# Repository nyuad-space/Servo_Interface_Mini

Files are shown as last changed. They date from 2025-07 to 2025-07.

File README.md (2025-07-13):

# Servo Interface Mini

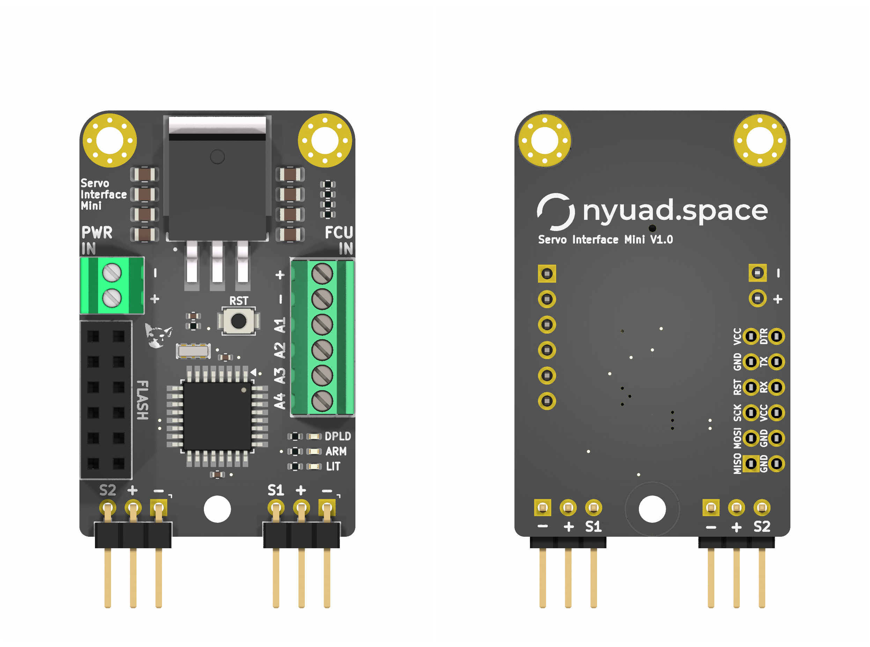
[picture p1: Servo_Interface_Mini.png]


## Overview

The **Servo Interface Mini** is a compact, flight-proven board built around the ATmega328P. It controls two servos via PWM based on logic changes on pyro channels. The board is part of our custom rocket parachute deployment system called the **Hold-Down Release Mechanism (HDRM)**.

It translates changes on pyro outputs from a flight computer into servo movement that actuates deployment hardware.

## Features

* **Microcontroller**: ATmega328P running Arduino-compatible firmware
* **Dual PWM Outputs**: Drives two standard hobby servos
* **Pyro Channel Triggering**: Responds to logic transitions on pyro lines
* **Status Indicators**: Onboard LEDs for deployment and system debugging
* **Power Supply**: Integrated LDO regulator supplies up to **5A at 5V** to servos and logic
* **Programming**: FTDI header for serial programming
* **Form Factor**: Compact layout with mounting holes for rugged, enclosed deployment

## Applications

* Servo-based parachute deployment systems
* Signal translation between flight computers and actuators
* Compact automation setups in rocketry and UAV systems

## Programming

The board is Arduino-compatible and programmed over an FTDI serial connection.

1. **Board Selection**: Choose **Arduino Pro Mini (5V, 16 MHz)** in the Arduino IDE
2. **Upload Method**: Use an FTDI-to-USB adapter connected to the 6-pin header
3. **Bootloader**: Compatible with standard Arduino bootloaders for ATmega328P

## Future Improvements

* Switch to **ATmega32U4** for native USB support and remove the need for an FTDI adapter

## Notes

* Pyro channel inputs are pulled up to 5V
* Designed for flight computers that ground pyro outputs (open-drain or active-low)
* Make sure servo current does not exceed 5A limit of onboard regulator
* Double check servo travel range to avoid overdriving linkages

**Disclaimer**: Use the files, hardware, and software in this repository at your own risk. We accept no responsibility for damage, failure, or unexpected behavior, especially during live flight tests.

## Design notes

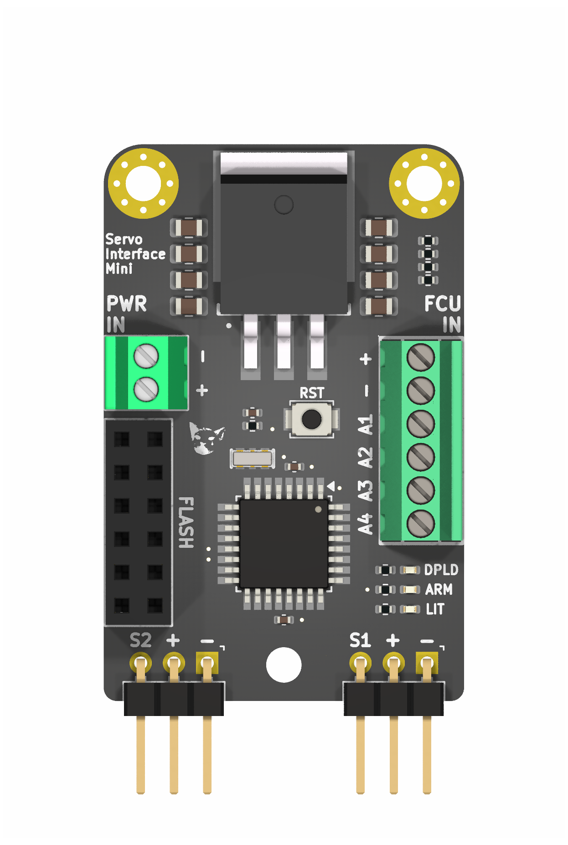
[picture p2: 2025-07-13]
hardware/Servo_Interface_Mini-F.png

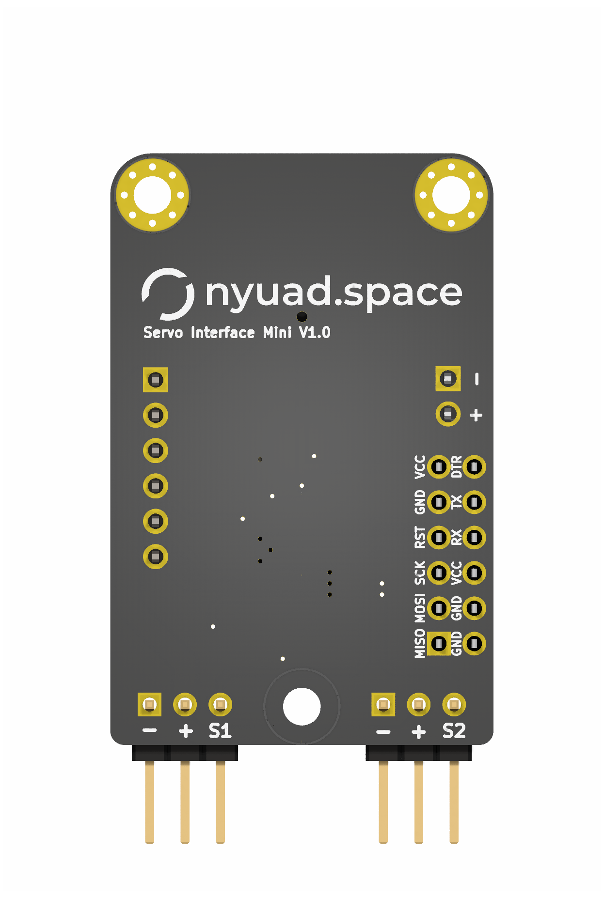
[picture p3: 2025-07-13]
hardware/Servo_Interface_Mini-B.png

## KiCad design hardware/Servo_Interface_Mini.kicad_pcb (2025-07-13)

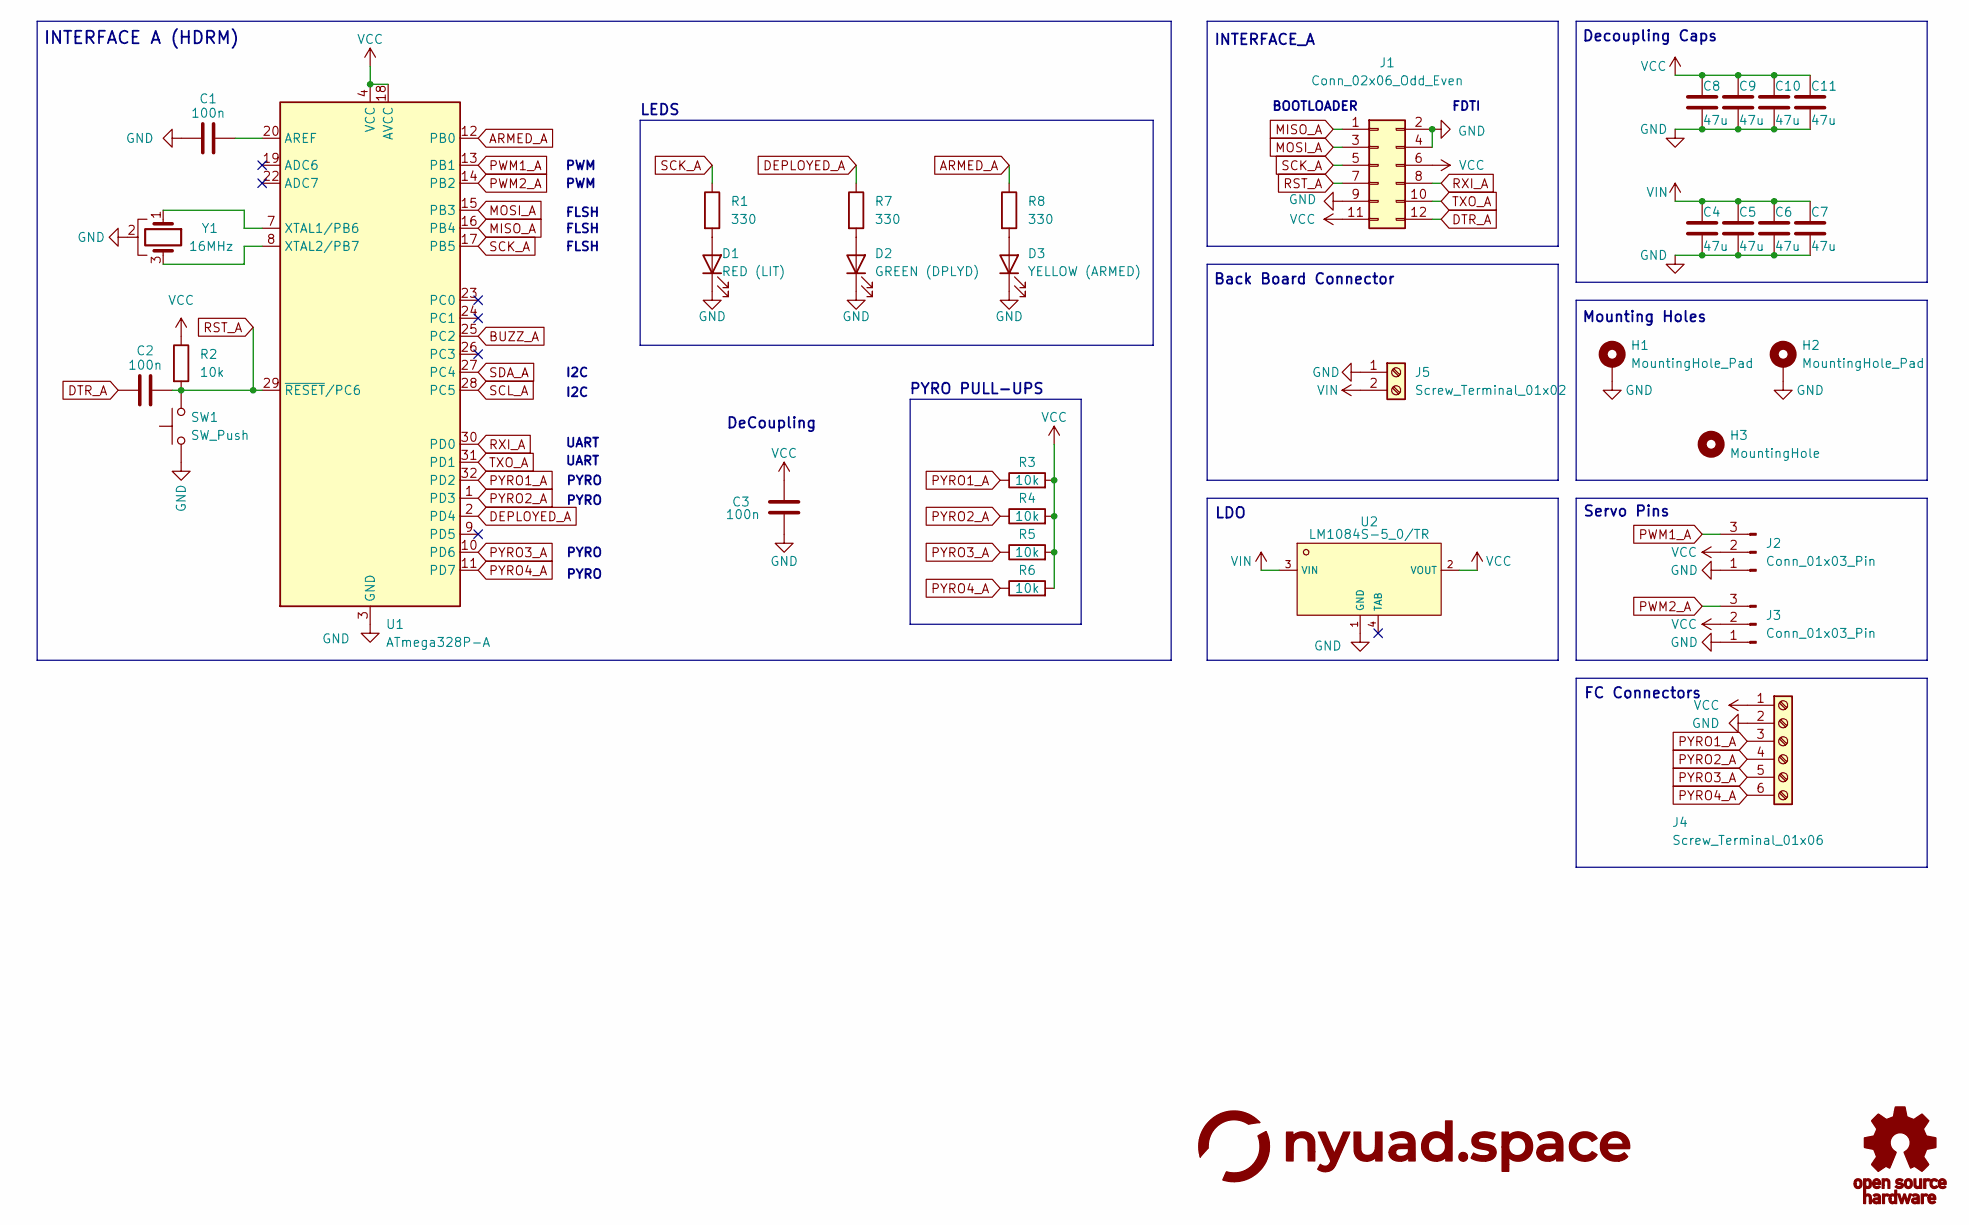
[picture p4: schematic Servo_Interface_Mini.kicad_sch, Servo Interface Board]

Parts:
C1, C2, C3: 100n; C_0402_1005Metric
C4, C5, C6, C7, C8, C9, C10, C11: 47u; C_0805_2012Metric
D1: RED (LIT); LED_0402_1005Metric
D2: GREEN (DPLYD); LED_0402_1005Metric
D3: YELLOW (ARMED); LED_0402_1005Metric
H1, H2: MountingHole_Pad; MountingHole_2.7mm_M2.5_Pad_Via
H3: MountingHole; MountingHole_2.7mm
J1: Conn_02x06_Odd_Even; HDR-TH_12P-P2.54-V-F-R2-C6-S2.54
J2, J3: Conn_01x03_Pin; PinHeader_1x03_P2.54mm_Horizontal
J4: Screw_Terminal_01x06; CONN-TH_DB125-2.54-6P-GN
J5: Screw_Terminal_01x02; CONN-TH_DB125-2.54-2P-GN
R1, R7, R8: 330; R_0402_1005Metric
R2, R3, R4, R5, R6: 10k; R_0402_1005Metric
SW1: SW_Push; SW_SPST_B3U-1000P
U1: ATmega328P-A; TQFP-32_7x7mm_P0.8mm
U2: LM1084S-5_0/TR; TO-263-3_L8.6-W10.2-P2.54-LS14.4-TL; LCSC C259973
Y1: 16MHz; OSC-SMD_3P-L3.2-W1.3-P0.95-L

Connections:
ARMED_A: R8.1, U1.12 (PB0)
BUZZ_A: U1.25 (PC2)
DEPLOYED_A: R7.1, U1.2 (PD4)
DTR_A: C2.1, J1.12
GND: C1.1, C3.1, C4.2, C5.2, C6.2, C7.2, C8.2, C9.2, C10.2, C11.2, D1.1 (K), D2.1 (K), D3.1 (K), H1.1, H2.1, J1.2, J1.4, J1.9, J2.1, J3.1, J4.2, J5.1, SW1.1, U1.3 (GND), U1.5 (GND), U1.21 (GND), U2.1 (GND), Y1.2
MISO_A: J1.1, U1.16 (PB4)
MOSI_A: J1.3, U1.15 (PB3)
unnamed: D1.2 (A), R1.2
unnamed: D2.2 (A), R7.2
unnamed: D3.2 (A), R8.2
unnamed: C1.2, U1.20 (AREF)
unnamed: U1.7 (XTAL1/PB6), Y1.1
unnamed: U1.8 (XTAL2/PB7), Y1.3
PWM1_A: J2.3, U1.13 (PB1)
PWM2_A: J3.3, U1.14 (PB2)
PYRO1_A: J4.3, R3.1, U1.32 (PD2)
PYRO2_A: J4.4, R4.1, U1.1 (PD3)
PYRO3_A: J4.5, R5.1, U1.10 (PD6)
PYRO4_A: J4.6, R6.1, U1.11 (PD7)
RST_A: C2.2, J1.7, R2.2, SW1.2, U1.29 (~RESET/PC6)
RXI_A: J1.8, U1.30 (PD0)
SCK_A: J1.5, R1.1, U1.17 (PB5)
SCL_A: U1.28 (PC5)
SDA_A: U1.27 (PC4)
TXO_A: J1.10, U1.31 (PD1)
VCC: C3.2, C8.1, C9.1, C10.1, C11.1, J1.6, J1.11, J2.2, J3.2, J4.1, R2.1, R3.2, R4.2, R5.2, R6.2, U1.4 (VCC), U1.6 (VCC), U1.18 (AVCC), U2.2 (VOUT)
VIN: C4.1, C5.1, C6.1, C7.1, J5.2, U2.3 (VIN)

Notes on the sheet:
FC Connectors
Servo Pins
Decoupling Caps
DeCoupling
FLSH
LEDS
UART
Back Board Connector
PYRO PULL-UPS
I2C
PYRO
INTERFACE A (HDRM)
PWM
LDO
Mounting Holes
FDTI
BOOTLOADER
INTERFACE_A

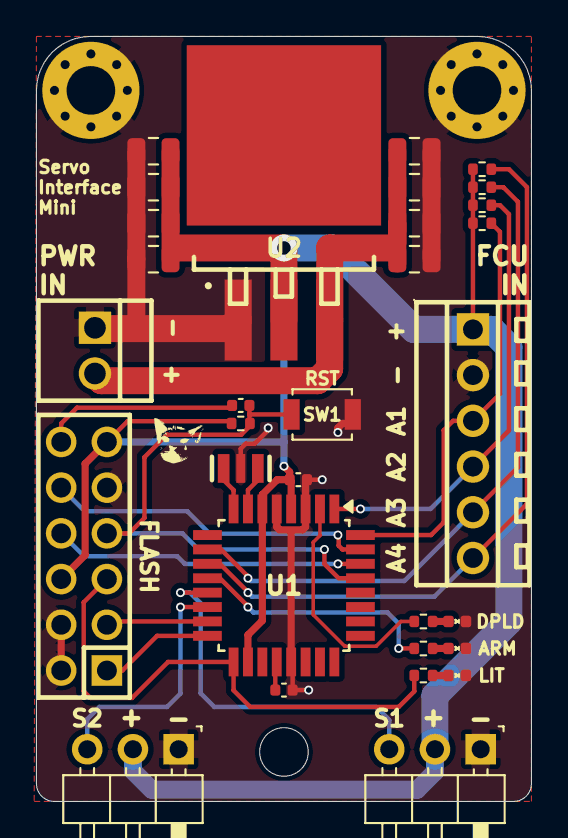
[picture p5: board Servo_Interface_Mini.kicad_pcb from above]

Board: 2 copper layers, 27.5 x 42.5 mm, 34 parts (0 on the bottom side), 24 nets.

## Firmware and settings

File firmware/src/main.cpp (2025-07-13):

#include "config.h"

Servo myServoA;
Servo myServoB;

unsigned long startTime = 0;
unsigned long endTime = 0;

int servoPinA = 9;
int servoPinB = 10;

int pos = 0;
bool armed = false;
bool servoTriggered = false;

void resetServo();
void triggerServo();
void ledBlink(int led, unsigned long delayTime);
void buzzerBeep(unsigned long beepInterval);

void setup()
{
  Serial.begin(9600);
  Serial.println("System initializing...");

  pinMode(pyroSignalA, INPUT);
  pinMode(pyroSignalB, INPUT);
  pinMode(pyroSignalC, INPUT);
  pinMode(pyroSignalD, INPUT);

  pinMode(ledLit, OUTPUT);
  pinMode(ledArmed, OUTPUT);
  pinMode(ledDeployed, OUTPUT);
  pinMode(buzzer, OUTPUT);

  myServoA.attach(servoPinA);
  myServoB.attach(servoPinB);

  myServoA.write(90);
  myServoB.write(90);
  
  delay(20);

  armed = true;
  Serial.println("System armed. Servos set to default positions.");
}

void loop()
{
  int pyroSignalOne = digitalRead(pyroSignalA);
  int pyroSignalTwo = digitalRead(pyroSignalB);
  int pyroSignalThree = digitalRead(pyroSignalC);
  int pyroSignalFour = digitalRead(pyroSignalD);

  Serial.print("Signals -> A: ");
  Serial.print(pyroSignalOne);
  Serial.print(" B: ");
  Serial.print(pyroSignalTwo);
  Serial.print(" C: ");
  Serial.print(pyroSignalThree);
  Serial.print(" D: ");
  Serial.println(pyroSignalFour);

  if (pyroSignalOne == 0 || pyroSignalTwo == 0 || pyroSignalThree == 0 || pyroSignalFour == 0)
  {
    Serial.println("Trigger condition met. Activating servos...");
    triggerServo();
  }

  if (armed)
  {
    ledBlink(ledArmed, 200);
  }
  else
  {
    ledBlink(ledDeployed, 500);
  }
}

void triggerServo()
{
  // for (pos = 0; pos <= 90; pos++)
  // {
  //   myServoA.write(pos);         // A moves 0 → 90
  //   myServoB.write(180 - pos);   // B moves 180 → 90
  //   delay(10);
  // }
  myServoA.write(160);
  myServoB.write(20);

  Serial.println("Servos triggered. System disarmed.");
  armed = false;
}

void resetServo()
{
  // for (pos = 90; pos >= 0; pos--)
  // {
  //   myServoA.write(pos);         // A moves 90 → 0
  //   myServoB.write(180 - pos);   // B moves 90 → 180
  //   delay(20);
  // }

  myServoA.write(2);
  myServoB.write(170);


  Serial.println("Servos reset. System rearmed.");
  armed = true;
}

void ledBlink(int led, unsigned long delayTime)
{
  if (millis() - endTime >= delayTime)
  {
    endTime = millis();
    digitalWrite(led, !digitalRead(led));
  }
}

void buzzerBeep(unsigned long beepInterval)
{
  unsigned long previousMillis = 0;
  bool buzzerState = false;

  pinMode(buzzer, OUTPUT);
  unsigned long currentMillis = millis();

  while (true)
  {
    if (currentMillis - previousMillis >= beepInterval)
    {
      previousMillis = currentMillis;
      buzzerState = !buzzerState;
      analogWrite(buzzer, buzzerState ? 2 : 0);
    }
    currentMillis = millis();
  }
}
